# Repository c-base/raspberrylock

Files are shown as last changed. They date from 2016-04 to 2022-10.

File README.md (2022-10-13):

Raspberry Lock
===============

The raspberry lock is a small application that runs on a Raspberry Pi with a
PiFace shield. It reads a 4-digit user-ID and a 4-6 digit passcode from a 4x4
matrix keypad. It then sends this data to a LDAP server to check if the
entered user-id and passcode combination is correct. If the server answers with
"correct", a door is opened by switching on an electric strike with a relais.

How to kill it
--------------

```
lsof -nP -iTCP -sTCP:LISTEN | grep 8888 | cut -w -f 2 | xargs kill -9
```

Installation
--------------

Install the piface module with the Raspberry Pi configuration tool:
```
sudo raspi-config (then follow the menu to Advanced -> SPI)

sudo apt-get install python3 python3-distutils python3-setuptools python3-dev libffi-dev libssl-dev rustc build-essential git
curl -sSL https://install.python-poetry.org | python3 -
git clone <repourl>
cd <reponame>
poetry install
sudo apt install libldap-2.4-2
sudo ln -s /usr/lib/arm-linux-gnueabihf/libldap_r-2.4.so.2 /usr/lib/arm-linux-gnueabihf/libldap.so
sudo ldconfig

```

Now clone this repository and change into its subdirectory.

Copy ```config.py.sample``` to ```config.py``` and change the password/binddn/pin field/group membership test for your application.

How To Run It
----------------

```
python3 schloss.py
```

Usage
----------------

Press A, then enter your 4 digit UID code, then press A again. Now enter your 4-6 digit PIN code and hit A.
If the code was correct, the door will open.

Hardware-Setup
----------------
```
+-----------------------------------------------------------------------+
|+---------------------------------------------------------------------+|
||+-------------------------------------------------------------------+||
|||+-----------------------------------------------------------------+|||
||||  +------+.................                                      ||||
||||  |      |                :                   +---------------+  ||||
|||+---+0    |  RASPBERRY PI  :                   |    KEYPAD     |  ||||
||+----+1    +--------+       :                   |               |  ||||
|+-----+2             |       :                   | 1   2   3   F |  ||||
+------+3             |       :                   | 4   5   6   E |  ||||
      |+4             +-------+                   | 7   8   9   D |  ||||
      |+5                     |                   | A   0   B   C |  ||||
      |+6                     ^                   |               |  ||||
      |+7                     |                   |               |  ||||
      |+0V                    +                   +---++++-++++---+  ||||
      |                       |    to LEDs            |||| ||||      ||||
      |                       |      ^ ^              |||| |||+------+|||
      |        PIFACE         |   Red| |Green         |||| ||+--------+||
      |                       |      | |              |||| |+----------+|
      |                       |      | |              |||| +------------+
      | ++                  7+-------+ |              ||||
      | ||                  6+---------+              ||||
      | ||                  5+------------------------+|||
      | ||                  4+-------------------------+||
      | ||  +----+ +----+   3+--------------------------+|
      | ||  |    | |    |   2+---------------------------+
      | ||  | R0 | | R1 |   1 |
      | ||  |    | |    |   0 |
      | ++  +----+ +----+ GND |
      |   .. +++    +++  +++ :|
      +-------------||--------+	        +-------------+
                    |+------------------| DOOR OPENER |-----+ +7.5V DC
                    |		            +-------------+
                    +---------------------------------------+ - (GND)
```

Additional Links
--------------------

* PiFace documentation: http://www.farnell.com/datasheets/1684425.pdf
* The keypad that we used looks somethink like this: http://uk.farnell.com/eao/eco-16250-06/keypad-4x4-matrix-0-02a-24v-plastic/dp/1130806

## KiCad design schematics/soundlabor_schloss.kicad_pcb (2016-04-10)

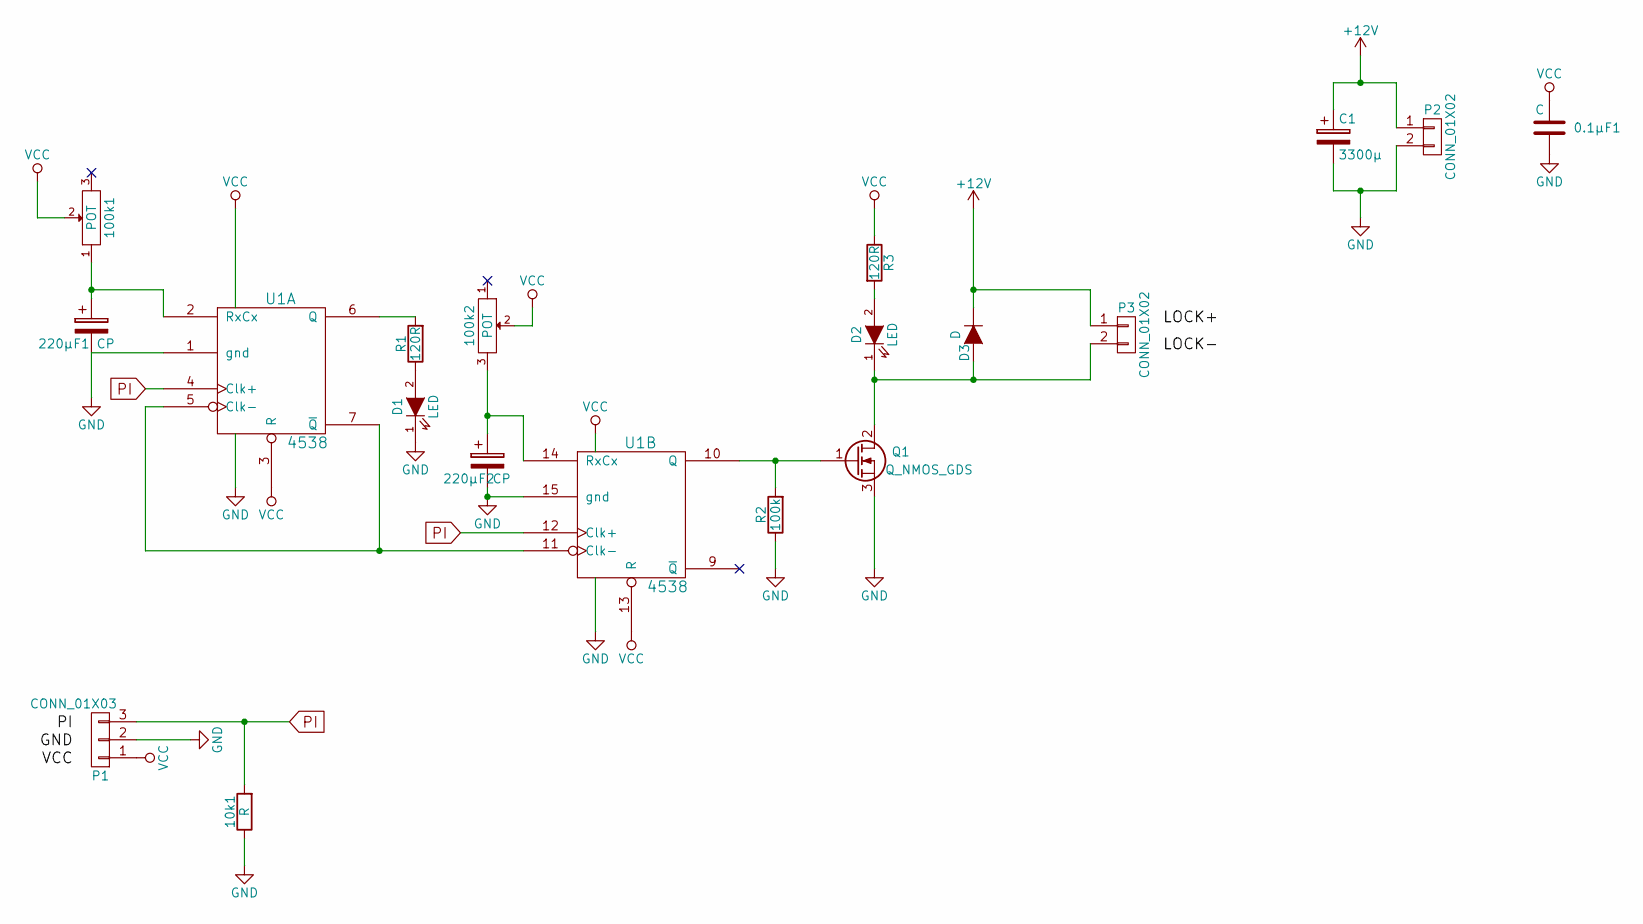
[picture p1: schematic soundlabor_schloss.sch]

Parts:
0.1µF1: C; C_Disc_D3_P2.5
10k1: R; Resistor_Horizontal_RM7mm
100k1, 100k2: POT; Potentiometer_Bourns_3006P_Angular_ScrewFront
220µF1, 220µF2: CP; C_Radial_D8_L11.5_P3.5
C1: 3300µ; ECA1EM332
D1, D2: LED; LED-5MM
D3: D; Diode_DO-41_SOD81_Horizontal_RM10
P1: CONN_01X03; Pin_Header_Angled_1x03
P2, P3: CONN_01X02; TerminalBlock_Pheonix_MKDS1.5-2pol
Q1: Q_NMOS_GDS; TO-220_Neutral123_Vertical
R1, R3: 120R; Resistor_Horizontal_RM7mm
R2: 100k; Resistor_Horizontal_RM7mm
U1: 4538; DIP-16_W7.62mm_LongPads

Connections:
+12V: C1.1, D3.1 (K), P2.1, P3.1
GND: 0.1µF1.1, 10k1.1, 220µF1.2, 220µF2.2, C1.2, D1.1 (K), P1.2, P2.2, Q1.3 (S), R2.1, U1.1 (gnd), U1.8 (VSS), U1.15 (gnd)
unnamed: 100k1.1, 220µF1.1, U1.2 (RxCx)
unnamed: 100k2.3, 220µF2.1, U1.14 (RxCx)
unnamed: D1.2 (A), R1.1
unnamed: D2.1 (K), D3.2 (A), P3.2, Q1.2 (D)
unnamed: D2.2 (A), R3.2
unnamed: Q1.1 (G), R2.2, U1.10 (Q)
unnamed: R1.2, U1.6 (Q)
unnamed: U1.5 (Clk-), U1.7 (~Q), U1.11 (Clk-)
PI: 10k1.2, P1.3, U1.4 (Clk+), U1.12 (Clk+)
VCC: 0.1µF1.2, 100k1.2, 100k2.2, P1.1, R3.1, U1.3 (R), U1.13 (R), U1.16 (VDD)

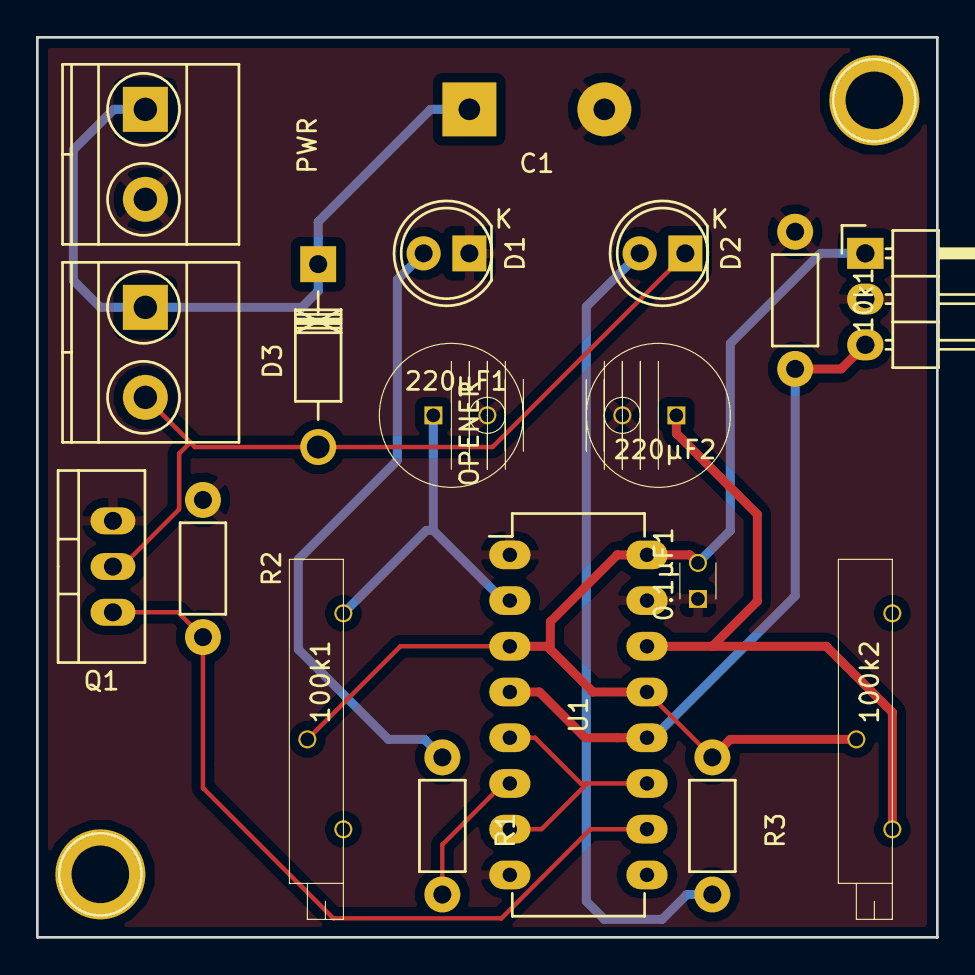
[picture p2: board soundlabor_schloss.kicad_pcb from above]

Board: 2 copper layers, 50.0 x 50.0 mm, 18 parts (0 on the bottom side), 12 nets.

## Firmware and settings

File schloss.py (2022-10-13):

#!/usr/bin/env python3

"""
c-lab schloss

Usage:
  schloss.py [--theme <theme>]
  schloss.py (-h | --help)
  schloss.py --version

Options:
  -h --help        Show this screen.
  --version        Show version.
  --theme=<theme>  Sound theme [default: default].
"""

import asyncio
import sys
import os
import time
import random
import subprocess

import uvloop
import gpiozero
from docopt import docopt
from ldap_interface import authenticate


from sanic import Sanic
from sanic.log import logger
from sanic.response import text

__version__ = '2.0.0'


# GPIO.setwarnings(False)

NUMERIC_KEYS = ['0', '1', '2', '3', '4', '5', '6', '7', '8', '9']

BOUNCE_TIME = 2  # in milliseconds
STALE_TIMEOUT = 30  # in seconds
timeouts = {'1': BOUNCE_TIME, '2': BOUNCE_TIME, '3': BOUNCE_TIME, '4': BOUNCE_TIME,
            '5': BOUNCE_TIME, '6': BOUNCE_TIME, '7': BOUNCE_TIME, '8': BOUNCE_TIME,
            '9': BOUNCE_TIME, '0': BOUNCE_TIME, 'A': BOUNCE_TIME, 'B': BOUNCE_TIME,
            'C': BOUNCE_TIME, 'D': BOUNCE_TIME, 'E': BOUNCE_TIME, 'F': BOUNCE_TIME}

Q = None
# Q = asyncio.queues.Queue()
# LOCK = RLock()

# ROWS and COLS for keyboard at HW lager
# ROWS = [24, 3, 5, 7]
# COLS = [15, 13, 11, 22]
# OPEN_PIN = 26

# Default ROWS, COLS and OPEN_PIN for all others
# ROWS = [11, 7, 5, 3]
# COLS = [16, 12, 10, 8]
ROWS = [17, 4, 3, 2]
COLS = [23, 18, 15, 14]
OPEN_PIN = 26

door_opener = None   # initialized by init_gpios()
keyboard_rows = []
keyboard_cols = []

PLAYER = 'aplay'

MONGO = None

STATE = 0
UID = ''
PIN = ''
RESET_TIMER = STALE_TIMEOUT

app = Sanic(__name__)


def next_theme():
    """
    Look into themes folder and find all installed themes. Get a random one which is not the current one.
    """
    global THEME
    themes = next(os.walk('./themes/'))[1]
    OLD_THEME = THEME
    while THEME != OLD_THEME:
        THEME = random.choice(themes)


def init_gpios():
    # GPIO.setmode(GPIO.BOARD)
    # GPIO.setup(OPEN_PIN, GPIO.OUT)
    global door_opener
    door_opener = gpiozero.LED(OPEN_PIN)
    door_opener.off()

    for pin in ROWS:
        out_pin = gpiozero.LED(pin)
        out_pin.off()
        keyboard_rows.append(out_pin)
    for pin in COLS:
        in_pin = gpiozero.Button(pin, pull_up=False)
        keyboard_cols.append(in_pin)


def decode_keypad(measurements):
    """
    x1 = (0,0,1,0)
    """
    layout = [['C', 'D', 'E', 'F'], ['B', '9', '6', '3'],
              ['0', '8', '5', '2'], ['A', '7', '4', '1']]
    for y_index, y_row in enumerate(measurements):
        for x_index, x_state in enumerate(y_row):
            if x_state > 0:
                return layout[y_index][x_index]
    return None   # No key pressed


def decrease_timeouts(timeouts):
    for k, v in timeouts.items():
        if v > 0:
            timeouts[k] = v - 1
    return timeouts


def collect_measurements():
    """
    """
    pin_state = []
    for y_pin in keyboard_rows:
        y_pin.on()
        x_pin_states = []
        for x_pin in keyboard_cols:
            pin_in = x_pin.value
            x_pin_states.append(pin_in)
        y_pin.off()
        pin_state.append(x_pin_states)
    return pin_state


def read_keypad():
    decrease_timeouts(timeouts)
    key = decode_keypad(collect_measurements())
    if key:
        if timeouts[key] > 0:
            return None
        else:
            num = random.randint(0, 9)
            subprocess.Popen([PLAYER, './themes/%s/%s.wav' % (THEME, num)],
                             stdout=subprocess.DEVNULL, stderr=subprocess.DEVNULL)
            print(PLAYER, './themes/%s/%s.wav' % (THEME, num))
            timeouts[key] = BOUNCE_TIME
            return key
    else:
        return None


def reset_state():
    global STATE, UID, PIN
    logger.debug("reset state")
    STATE = 0
    UID = ''
    PIN = ''


@app.add_task
async def timeout_reset_state():
    reset_state()   # first at the beginning
    global RESET_TIMER
    loop = asyncio.get_running_loop()
    while loop.is_running:
        RESET_TIMER -= 1
        logger.debug("timeout in %d" % RESET_TIMER)
        if RESET_TIMER <= 0:
            reset_state()
            RESET_TIMER = STALE_TIMEOUT
        await asyncio.sleep(1.0)


@app.add_task
async def control_loop():
    global Q
    if not Q:
        Q = asyncio.queues.Queue()

    global RESET_TIMER
    global STATE, UID, PIN
    reset_state()

    # Main state machine.
    # Expects the user to enter her UID, then PIN like this:
    # [A] 2903 [A] 123456 A
    # The first and second 'A' presses are optional and ignored for compatibility with the replicator.
    # The second 'A' would be mandatory for a non-4-digit UID, luckily all c-base UIDs are 4-digit, though.
    loop = asyncio.get_running_loop()
    while loop.is_running:
        key = await Q.get()
        print('state={}, got symbol {}'.format(STATE, '#'))
        RESET_TIMER = STALE_TIMEOUT
        Q.task_done()
        if STATE == 0:
            if key == 'A':
                # print('Enter UID:')
                STATE = 0
                continue
            elif key == 'C':
                reset_state()
                continue
            elif key in NUMERIC_KEYS:
                UID += key
                STATE = 1
                continue
        elif STATE == 1:
            if key in NUMERIC_KEYS:
                if len(UID) < 4:
                    UID += key
                    STATE = 1
                else:
                    PIN += key
                    STATE = 2
                continue
            elif key == 'C':
                reset_state()
                continue
            elif key == 'A':
                STATE = 2
                continue
        elif STATE == 2:
            if key in NUMERIC_KEYS:
                PIN += key
                continue
            elif key == 'C':
                reset_state()
                continue
            elif key == 'A':
                loop = asyncio.get_running_loop()
                # Start the LDAP check
                await open_if_correct(UID, PIN)
                reset_state()
                continue


async def open_if_correct(uid, pin):
    """
    BLOCKING! Maybe this function needs to run in an executor thread.
    """
    print('checking ldap ...')
    try:
        if authenticate(uid, pin):
            subprocess.Popen([PLAYER, './themes/%s/success.wav' % THEME],
                             stdout=subprocess.DEVNULL, stderr=subprocess.DEVNULL)
            next_theme()
            door_opener.on()
            await asyncio.sleep(1)
            door_opener.off()
            await asyncio.sleep(8)

        else:
            subprocess.Popen([PLAYER, './themes/%s/fail.wav' % THEME],
                             stdout=subprocess.DEVNULL, stderr=subprocess.DEVNULL)
            await asyncio.sleep(2)
    except Exception as error:
        print(error)
        subprocess.Popen([PLAYER, './themes/%s/error.wav' % THEME],
                         stdout=subprocess.DEVNULL, stderr=subprocess.DEVNULL)
        await asyncio.sleep(2)


@app.add_task
async def keypad_loop():
    global Q
    if not Q:
        Q = asyncio.queues.Queue()
    loop = asyncio.get_running_loop()
    while loop.is_running:
        key = read_keypad()
        if key:
            await Q.put(key)
        await asyncio.sleep(0.1)
    
    

@app.get("/")
async def hello_world(request):
    return text(f"Next timeout in %d" % RESET_TIMER)
    

if __name__ == '__main__':
    args = docopt(__doc__, version=__version__)
    try:
        THEME = args['--theme']
        init_gpios()
        app.run(host="0.0.0.0", port=8888, debug=True, access_log=True)
    except KeyboardInterrupt:
        print('quitting')

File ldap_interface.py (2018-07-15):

#!/usr/bin/env python3
# -*- coding: utf-8 -*-

import base64
import hashlib
from datetime import datetime

from lmap import *

import config

def ldap_connect():
	ld = ldap.ldap(config.LDAP.URI)
	ld.simple_bind(config.LDAP.BINDDN, config.LDAP.BINDPW)
	return lmap.lmap(dn=config.LDAP.BASE, ldap=ld), ld


def pwcheck(record, pw):
	if not record.startswith('{SSHA}'):
		return record == pw
	bd = base64.b64decode(bytearray(record[6:], 'UTF-8'))
	hashv = bd[:20]
	salt = bd[20:]
	newhashv = hashlib.sha1(bytearray(pw, 'UTF-8')+salt).digest()
	return hashv == newhashv


def authenticate(uid, pin):
	lm, ld = ldap_connect()
	try:
		user = lm(config.LDAP.USERBASE).search(config.LDAP.ACCESS_FILTER.format(uid))[0]
		username = user[config.LDAP.UIDFIELD]
		if pwcheck(user[config.LDAP.PINFIELD], pin):
			print(datetime.now(), 'Valid combination for user "%s". Opening lock' % username)
			ld.close()
			return True
	except Exception as e:
		print(datetime.now(), 'Invalid user/pin:', uid, '('+str(e)+')')
	ld.close()
	return False


numbuf = []


if __name__ == "__main__":
	print(pwcheck('{SSHA}c8pLDYbSkF2jBAKxxa67nY7NYkdQXiPNFzzRso9FRZI=', '1234'))

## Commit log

2013-10-20 Initial commit, works on the raspberry pi
2013-10-20 Add Schematic
2013-10-20 Power supply and summer added
2013-10-20 Fixed schematic
2013-10-25 added timeout and fixed merge request
    [schloss.py]
2015-05-14 auslesen der tasten geht
2015-09-12 Adding KiCad schematic files and such.
    [soundlabor_schloss.kicad_pcb, soundlabor_schloss.sch]
2015-09-12 Finishing basic PCB design. Feel free to improve on it. Uses a ground back plane and otherwise routes everything on front layer
    [soundlabor_schloss.kicad_pcb, soundlabor_schloss.sch]
2016-04-02 pcb done
    [soundlabor_schloss.sch]
2016-04-09 did... something
    [soundlabor_schloss.kicad_pcb]
2016-04-09 improved circuit
    [soundlabor_schloss.sch]
2016-04-10 final version
    [soundlabor_schloss.kicad_pcb, soundlabor_schloss.sch]
2017-05-01 some changes to schematics
